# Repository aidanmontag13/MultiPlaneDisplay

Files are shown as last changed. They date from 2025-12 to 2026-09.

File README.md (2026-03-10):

# MultiPlaneDisplay

<p align="center">
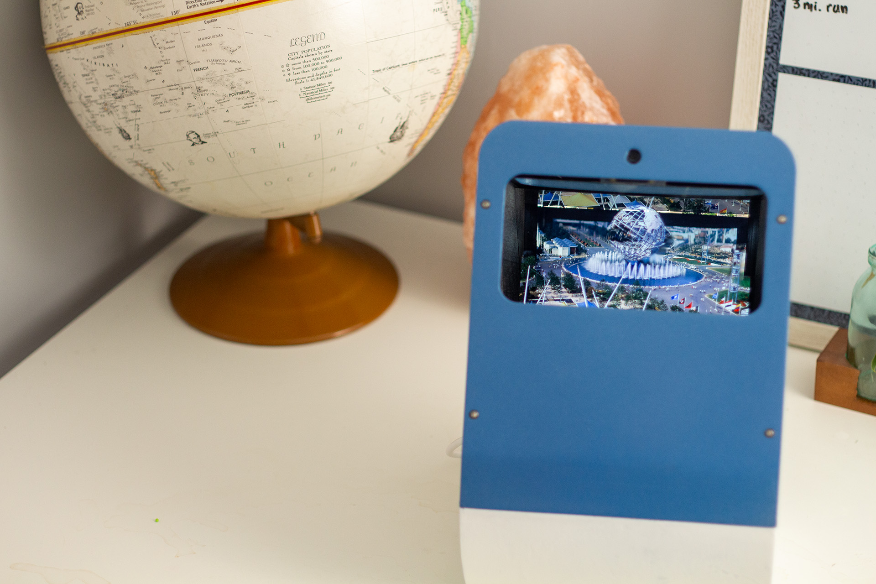
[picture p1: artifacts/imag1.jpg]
  
</p>

# How does it work?
Multi-Plane Display uses image processing and Pepper's Ghost illusions to enable any photo to be viewed with real depth, creating a "2 and a half D" Illusion.
<p align="center">
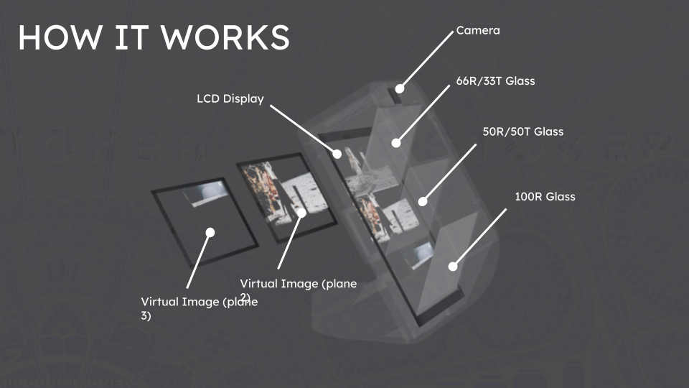
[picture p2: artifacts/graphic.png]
  
</p>

## Workflow

1. **Depth segmentation**  
   A depth map is extracted from the image using *Depth Anything v2* and used to segment the scene into **foreground**, **middleground**, and **background** layers.

2. **Viewer tracking**  
   Monocular head tracking estimates the viewer’s position relative to the display.

3. **Shadow correction**  
   Shadow maps are dynamically adjusted based on the viewer’s position to prevent off-axis ghosting artifacts.

4. **Optical display**  
   The layered images are displayed through a parascope mirror array, producing the virtual display stacking effect.
   
<table align="center">
  <tr>
    <td align="center">
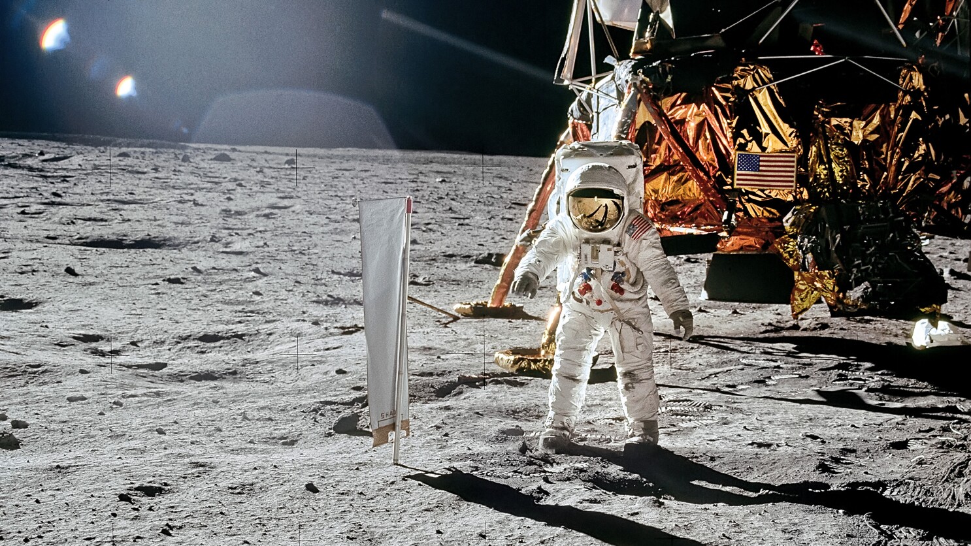
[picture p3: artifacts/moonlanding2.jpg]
      <br>
      <sub>Input Image</sub>
    </td>
    <td align="center">
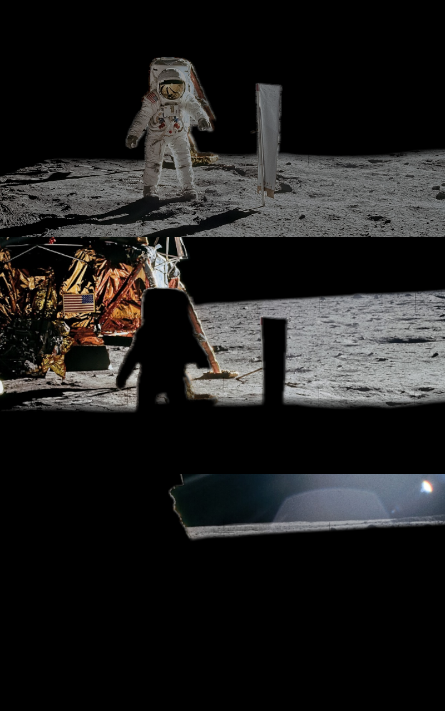
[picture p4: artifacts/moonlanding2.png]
      <br>
      <sub>Processed Image</sub>
    </td>
    <td width="40"></td>
    <td align="center">
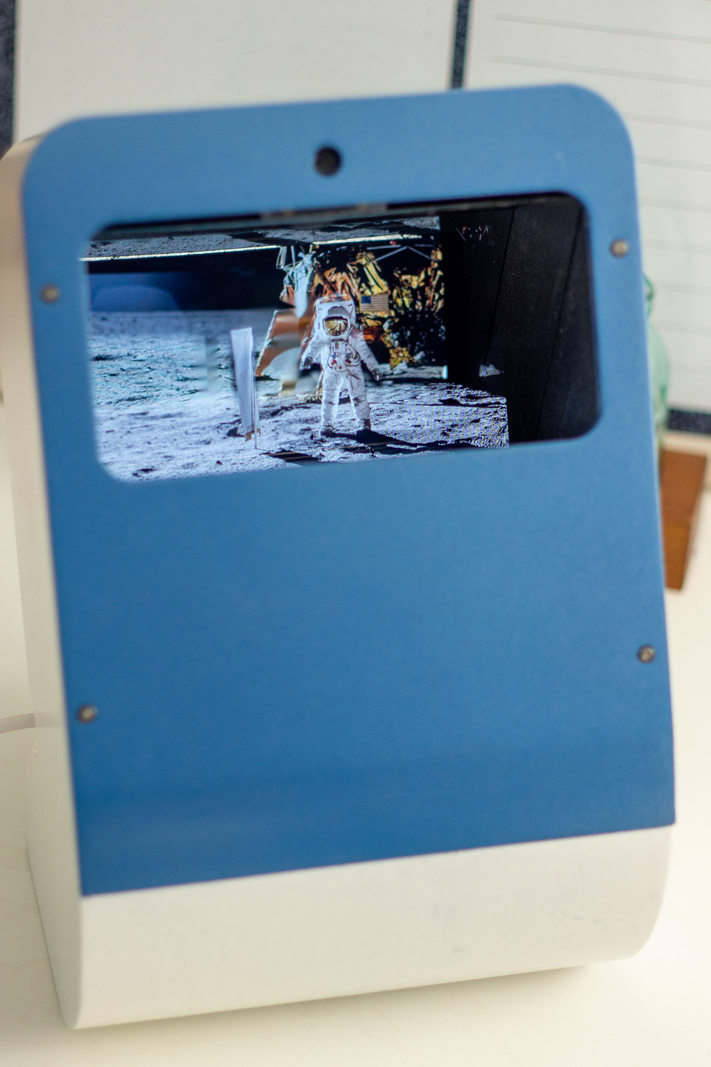
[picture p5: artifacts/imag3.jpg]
      <br>
      <sub>Viewable Result</sub>
    </td>
  </tr>
</table>

## Gallery
<p align="center">
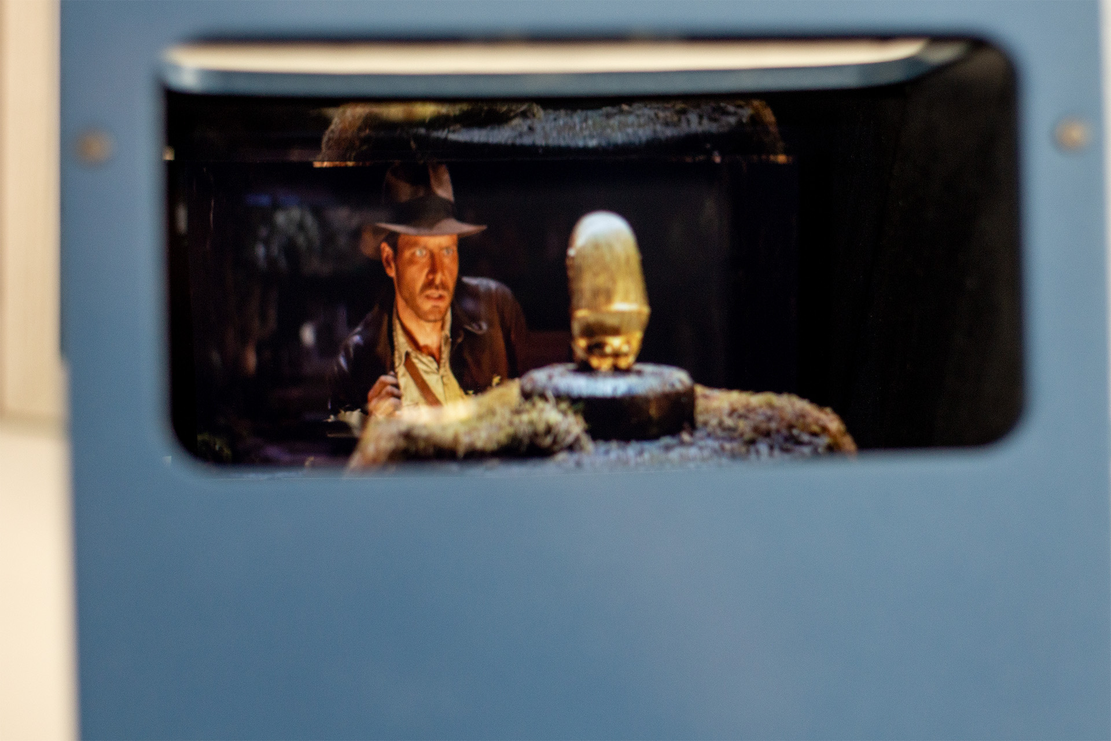
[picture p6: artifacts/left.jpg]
  
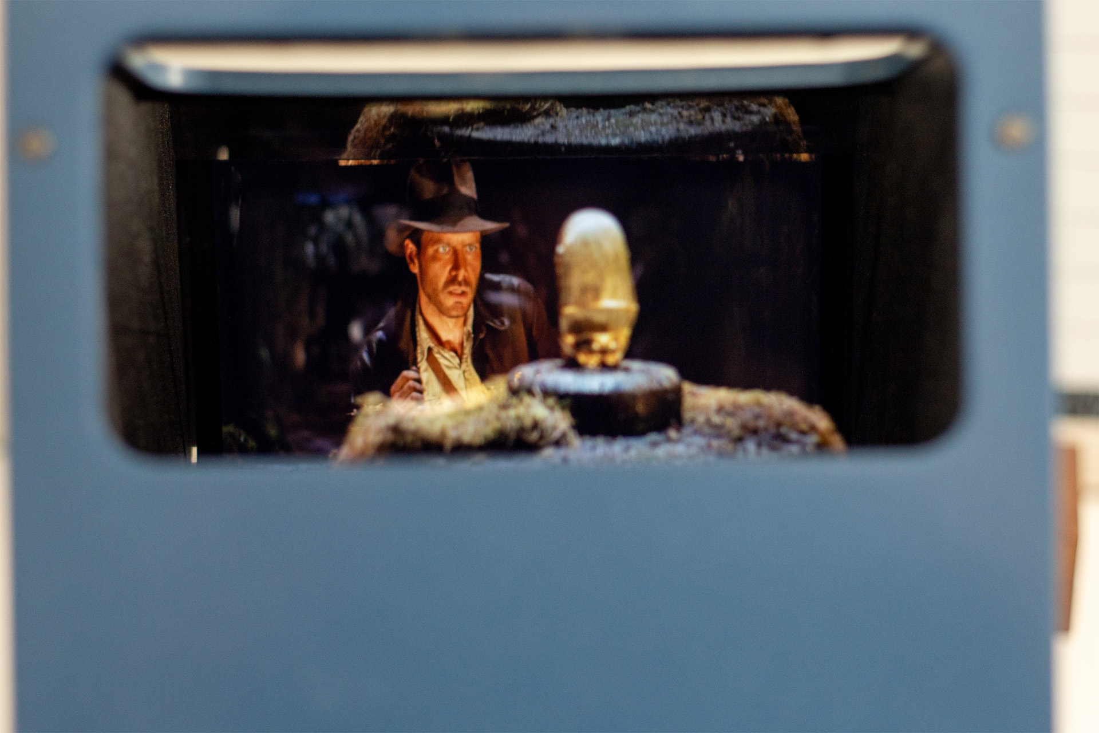
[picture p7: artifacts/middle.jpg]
  
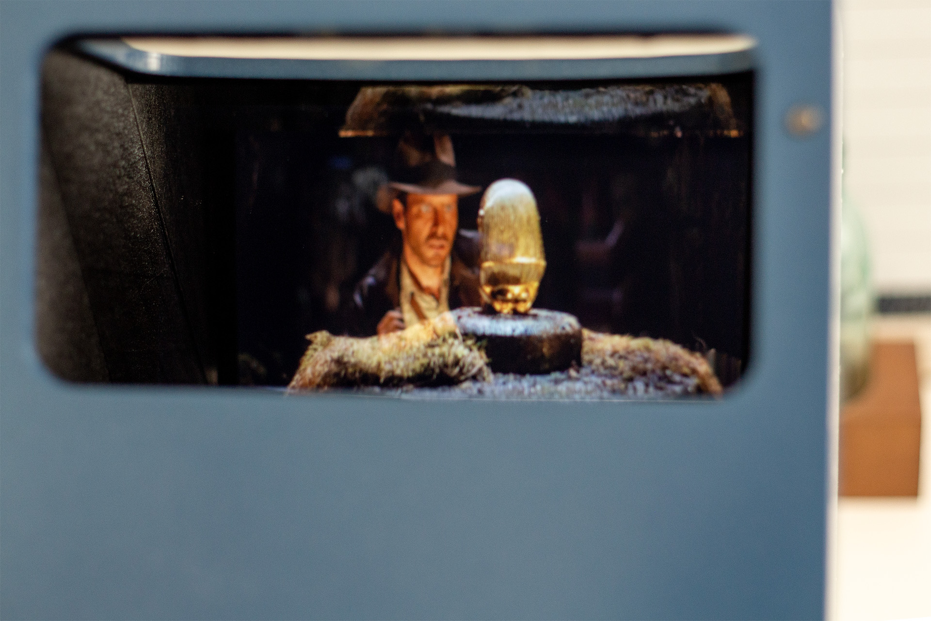
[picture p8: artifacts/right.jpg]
  
</p>

<p align="center">
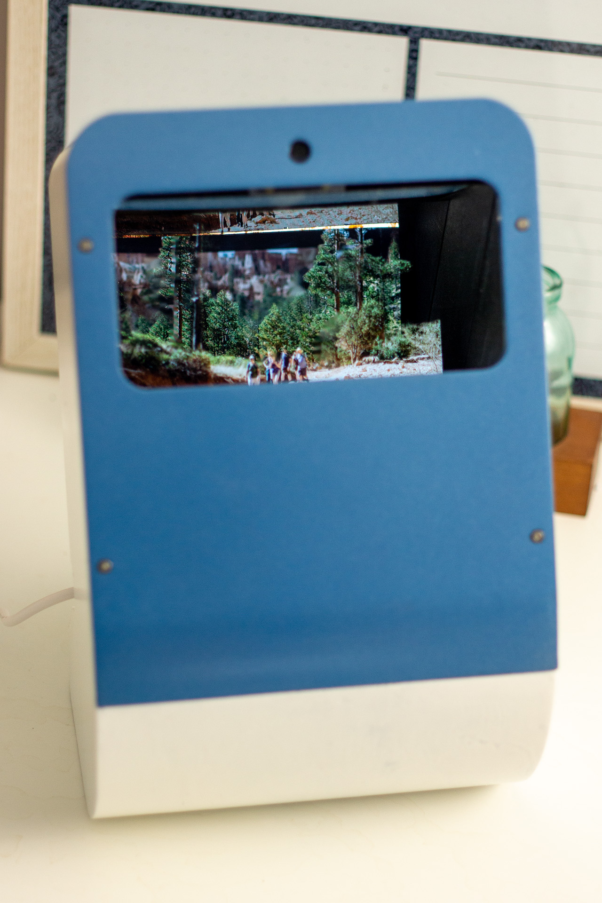
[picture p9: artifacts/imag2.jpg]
  
</p>

## Features
- Automatic image processing with input from USB drive
- Compatibility with .jpg, .jpeg, .png, and .tiff
- Automated occlusion maps with real-time headtracking
- Automatic Display turn-off and idle mode when unobserved for 30 seconds

## Parts List

- Waveshare 10.1" Display  https://a.co/d/bgIxvvW
- Raspberry Pi 5  https://a.co/d/f5K5WJR
- Cooling Fan  https://a.co/d/cPdcFge
- Semi-reflective acrylic (162x110mm) (optimally use 66/33 and 50/50 teleprompter glass, but this stuff is cheap)  https://a.co/d/37wRoJS
- acrylic mirror  (162x110mm) https://a.co/d/5MYHUT7 
- 8MP camera  https://a.co/d/0b0CgG3
- RPi 5 PSU  https://a.co/d/g17dBXe
- Micro SD card  https://a.co/d/0lqvz4a
- USB Drive  https://a.co/d/dX8yHnJ
- 250 mm CSI cable  https://a.co/d/1fIMcX2

INSTALLATION

1. Configure the Raspberry Pi camera and display

Edit the firmware configuration file:

```
sudo nano /boot/firmware/config.txt
```

Change this line:

```
camera_auto_detect=1
```

to:

```
camera_auto_detect=0
```

Add the following lines to the bottom of the file:

```
dtoverlay=vc4-kms-v3d
dtoverlay=vc4-kms-dsi-waveshare-panel-v2,10_1_inch_a
dtoverlay=imx219,cam0
```

Save the file and reboot the system.

---

2. Install system dependencies

Update the system:

```
sudo apt update
sudo apt upgrade
```

Install required packages:

```
sudo apt install -y python3-libcamera
sudo apt install -y libcamera-apps libcamera-dev libcamera-tools
sudo apt install -y python3-picamera2
sudo apt install -y unclutter
sudo apt install -y libcap-dev
```

---

3. Clone the repository

```
git clone https://github.com/aidanmontag13/MultiPlaneDisplay.git
cd MultiPlaneDisplay
```

---

4. Create the Python environment

Create a virtual environment with access to system packages (required for libcamera):

```
python3 -m venv venv --system-site-packages
```

Activate the environment:

```
source venv/bin/activate
```

Install Python dependencies:

```
pip install -r requirements.txt
```

---

5. Install the systemd service

Move the service file:

```
sudo mv ~/MultiPlaneDisplay/run_multiplane.service /etc/systemd/system/
```

Reload systemd:

```
sudo systemctl daemon-reload
```

Start the service:

```
sudo systemctl start run_multiplane.service

sudo systemctl enable run_multiplane.service
```

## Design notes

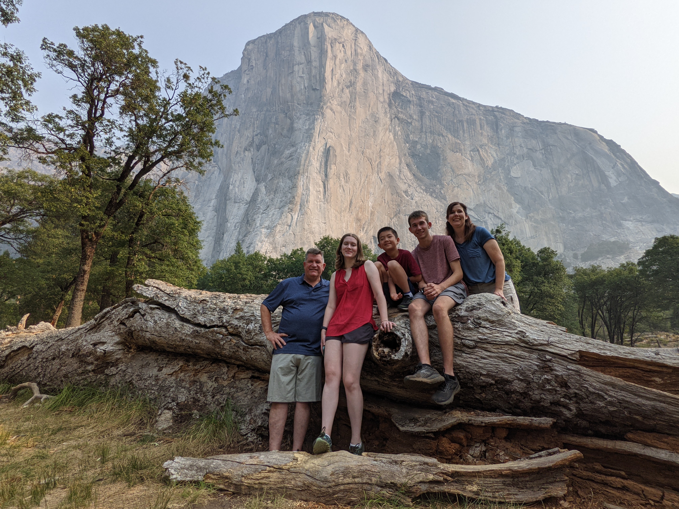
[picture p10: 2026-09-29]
image.jpg

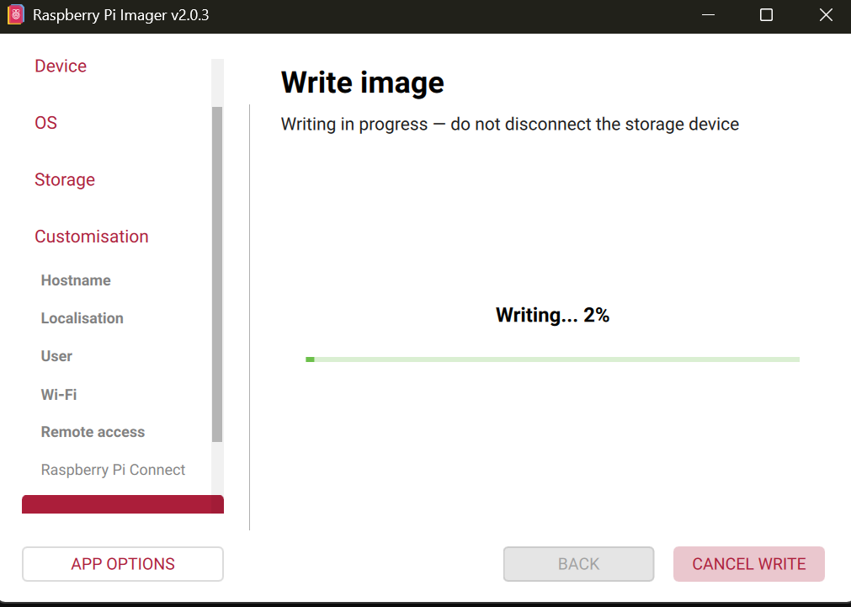
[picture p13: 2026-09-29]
artifacts/imager.png

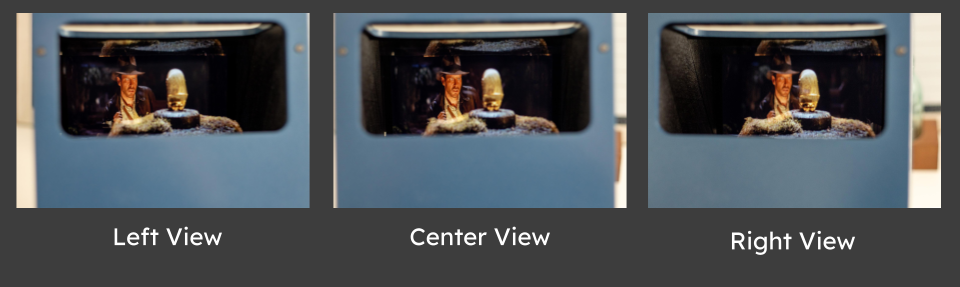
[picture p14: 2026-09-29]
artifacts/views.png

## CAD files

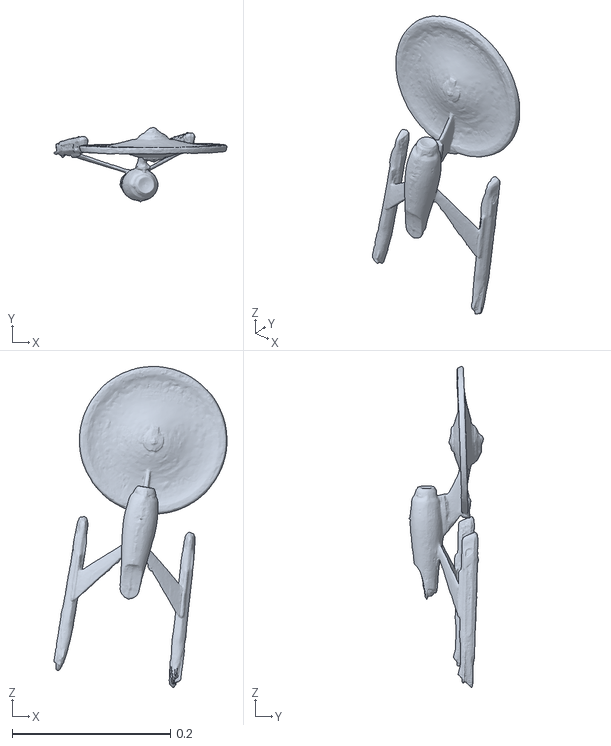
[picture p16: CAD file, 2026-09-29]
3Dmodels/model.obj
0.219 x 0.0944 x 0.406

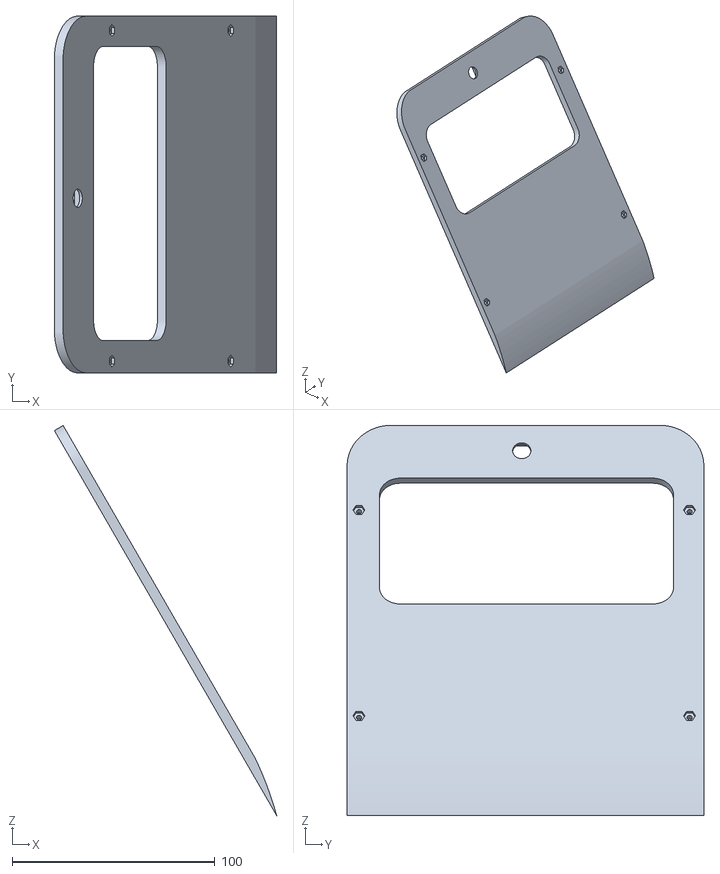
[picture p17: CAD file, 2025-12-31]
STLs/MultiplaneLid.stl
109.7 x 176.0 x 192.4

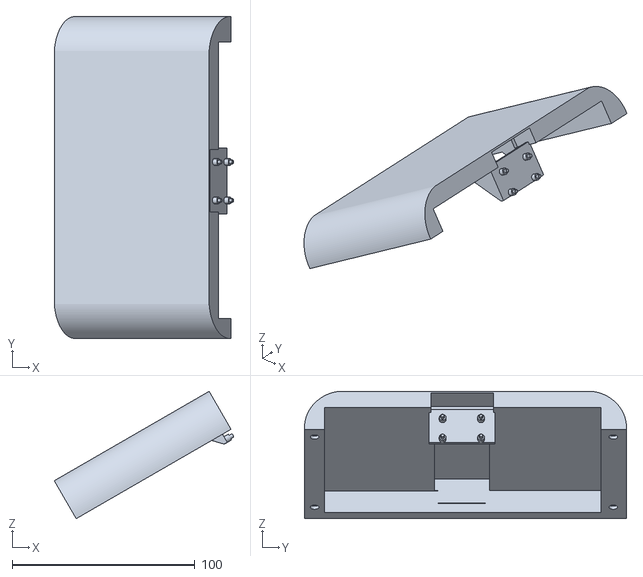
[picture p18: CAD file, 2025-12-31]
STLs/MultiplaneCap.stl
98.1 x 176.0 x 69.6

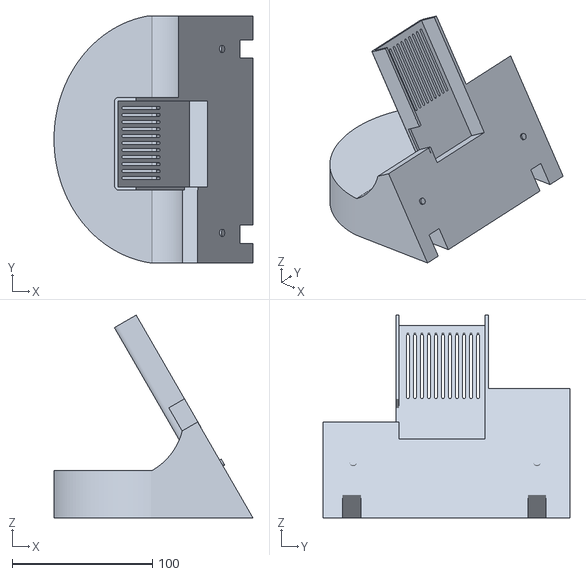
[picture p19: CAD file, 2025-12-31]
STLs/MultiplaneStand.stl
141.8 x 176.0 x 144.6

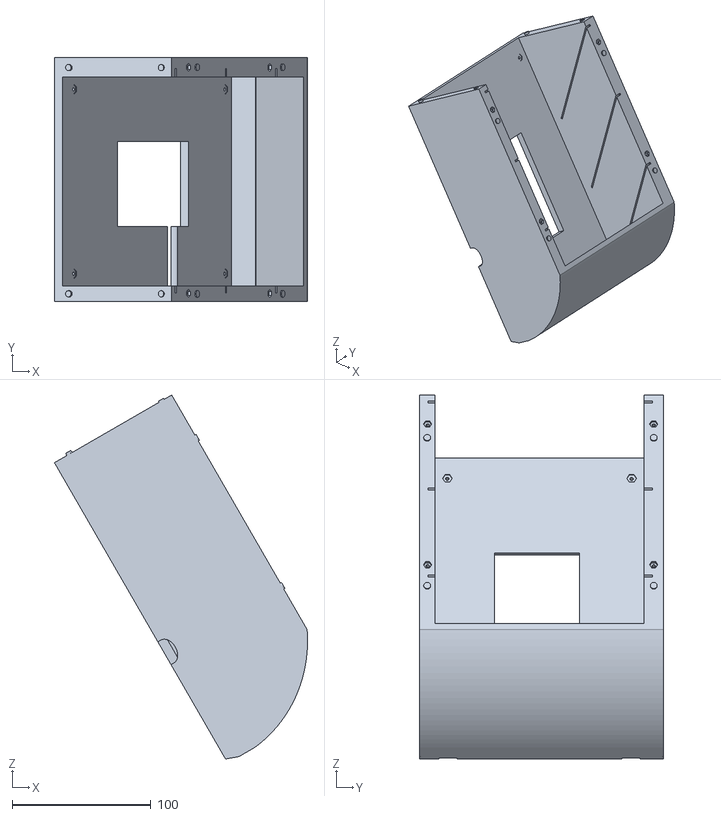
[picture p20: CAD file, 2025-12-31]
STLs/MultiplaneBase.stl
182.7 x 176.0 x 262.7

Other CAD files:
model.obj

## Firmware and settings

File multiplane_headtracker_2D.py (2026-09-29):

from math import sqrt
import onnxruntime as ort
import cv2
import numpy as np
import glob
import os
import time
import copy
import subprocess
import argparse

from skimage.filters import threshold_multiotsu

import headtracker
import queue
import threading
from ultralytics import YOLO

H = 426
W = 800

PROJECTION_DISTANCE = 0.3
SCREEN_0_DISTANCE = 0.0
SCREEN_1_DISTANCE = 0.07
SCREEN_2_DISTANCE = 0.14
DEPTH_RANGE = 0.21718
DISPLAY_WIDTH = 0.13596

ALL_DISPLAY_V_OFFSET = -10
DISPLAY_1_V_OFFSET = 10
DISPLAY_2_V_OFFSET = 30

CAMERA_V_OFFSET = 30
CAMERA_H_OFFSET = 0

CAMERA_V_OFFSET_2 = 50
CAMERA_H_OFFSET_2 = 0

DISPLAY_1_SHIFT_SCALER = 0.85
DISPLAY_2_SHIFT_SCALER = 0.4

DISPLAY_1_MAGNIFY_SCALER = 1.05
DISPLAY_2_MAGNIFY_SCALER = 1.1

ROLLOFF_A = 0.07
ROLLOFF_B = 0.15

# Load model
session = ort.InferenceSession(
    "models/depth_anything/depth_anything_v2_vits.onnx",
    providers=['CPUExecutionProvider']
)

# Get correct input name
input_name = session.get_inputs()[0].name

segment_model = YOLO("yolov8m-seg.pt")

def find_usb_images():
    user = "multiplane"
    media_root = f"/media/{user}"

    image_paths = []

    # Loop over all USB drives
    for drive in os.listdir(media_root):
        drive_path = os.path.join(media_root, drive)
        images_folder = os.path.join(drive_path)

        if os.path.isdir(images_folder):
            print(f"Found images folder on USB: {images_folder}")

            # Add all image files (jpg, png, tiff)
            for ext in ("*.jpg", "*.jpeg", "*.png", "*.tif", "*.tiff"):
                image_paths.extend(glob.glob(os.path.join(images_folder, ext)))
        else:
            print(f"No images folder found on USB: {drive_path}")
            continue

    return image_paths

def resize_and_crop(img):
    h, w = img.shape[:2]

    if w/h < 1:
        border_size = int((h - w * 1) / 2)
        img = cv2.copyMakeBorder(
            img, 0, 0, border_size, border_size,
        borderType=cv2.BORDER_CONSTANT,
        value=[0, 0, 0]
    )

    h, w = img.shape[:2]
    
    # Compute scale factor to cover the target
    scale = W / w
    
    # Resize image
    new_w = int(w * scale)
    new_h = int(h * scale)
    #print(f"Resizing from ({w}, {h}) to ({new_w}, {new_h})")
    if w / h > W / H:
        resized = cv2.resize(img, (new_w, H), interpolation=cv2.INTER_LINEAR)
        start_x = (new_w - W) // 2
        cropped = resized[:, start_x:start_x + W]
    else:
        resized = cv2.resize(img, (W, new_h), interpolation=cv2.INTER_LINEAR)
        start_y = (new_h - H) // 2
        cropped = resized[start_y:start_y + H, :]
    
    return cropped

def preprocess(image):
    img = cv2.cvtColor(image, cv2.COLOR_BGR2RGB)
    img = cv2.resize(img, (518, 518))
    img = img.astype(np.float32) / 255.0

    # model normalization
    mean = np.array([0.5, 0.5, 0.5], dtype=np.float32)
    std  = np.array([0.5, 0.5, 0.5], dtype=np.float32)
    img = (img - mean) / std

    img = img.transpose(2, 0, 1)  # HWC → CHW
    img = img[None, ...]          # add batch dim
    return img

def infer(inp):
    out = session.run(None, {input_name: inp})
    depth = out[0][0]

    # rescale depth for saving
    depth = (depth - depth.min()) / (depth.max() - depth.min())
    return depth

def despeckle(mask, kernel_size):
    kernel = np.ones((kernel_size,kernel_size), np.uint8)   # or (5,5) depending on outline thickness
    mask = mask * -1 + 1
    mask = (mask * 255).astype(np.uint8)
    closed = cv2.morphologyEx(mask, cv2.MORPH_CLOSE, kernel)
    mask = (closed.astype(np.float32)) / 255.0
    mask = mask * -1 + 1
    return mask

def blur_and_dilate(mask, blur_size):
    mask = mask * -1 + 1
    kernel = np.ones((int(blur_size * 0.2), int(blur_size * 0.8)), np.uint8)
    mask_uint8 = (mask * 255).astype(np.uint8)
    expanded = cv2.dilate(mask_uint8, kernel)
    mask = expanded.astype(np.float32) / 255.0
    mask = mask * -1 + 1
    mask = cv2.GaussianBlur(mask, (blur_size * 3, blur_size), 0)
    return mask

def create_mask(depth, low_thresh, high_thresh, rolloff_a, rolloff_b, blur):
    mask = np.zeros_like(depth, dtype=np.float32)

    if rolloff_a == 0 and rolloff_b == 0:
        mask = ((depth >= low_thresh) & (depth <= high_thresh)).astype(np.float32)
        mask = blur_and_dilate(mask, blur)
        mask = despeckle(mask, kernel_size=3)
        mask = cv2.resize(mask, (W, H), interpolation=cv2.INTER_LINEAR)
        return mask
    
    lower_ramp = (depth - (low_thresh - 0.5 * rolloff_a)) / (rolloff_a + 1e-6)
    lower_ramp = np.clip(lower_ramp, 0, 1)
    
    upper_ramp = ((high_thresh + 0.5 * rolloff_b) - depth) / (rolloff_b + 1e-6)
    upper_ramp = np.clip(upper_ramp, 0, 1)
    
    if low_thresh == 0:
        mask = upper_ramp
    elif high_thresh == 1:
        mask = lower_ramp
    else:
        mask = np.minimum(lower_ramp, upper_ramp)

    mask = despeckle(mask, kernel_size=3)
    mask = blur_and_dilate(mask, blur)

    mask = cv2.resize(mask, (W, H), interpolation=cv2.INTER_LINEAR)
    
    return mask

def apply_mask(image, mask):
    mask = np.repeat(mask[:, :, np.newaxis], 3, axis=2)
    masked_image = image * mask
    return masked_image

def create_segmentation_mask(image):
    image = cv2.resize(image, (640, 640))

    results = segment_model(image)
    result = results[0]

    if result.masks is None:
        return None

    masks = result.masks.data.cpu().numpy()
    mask = (np.sum(masks, axis=0)).astype(np.float32)
    mask = np.clip(mask, 0, 1).astype(np.float32)
    #mask = cv2.GaussianBlur(mask, (25, 25), 0)

    return masks

def apply_segmentation_mask(mask, segmentation_masks, blur):
    if segmentation_masks is None:
        return mask

    solid_mask = mask.copy()

    for segmentation_mask in segmentation_masks:
        segmentation_mask = segmentation_mask.astype(np.float32)
        segmentation_mask = cv2.resize(segmentation_mask, (mask.shape[1], mask.shape[0]), interpolation=cv2.INTER_LINEAR)

        ratio = np.sum(segmentation_mask * mask) / (np.sum(segmentation_mask))
        print("ratio is:", ratio)

        if ratio > 0.5 and ratio < 0.9:
            solid_mask = np.where((segmentation_mask >= solid_mask) & (solid_mask > 0.1), segmentation_mask, solid_mask)

        if ratio <= 0.5:
            solid_mask = np.where((segmentation_mask >= solid_mask) & (solid_mask > 0.1), 0, solid_mask)

        solid_mask = np.clip(solid_mask, 0, 1)
        solid_mask = cv2.GaussianBlur(solid_mask, (blur * 3, blur), 0)

    stacked_vis = np.vstack((mask, solid_mask))
    #cv2.imshow("stacked visualization", ((stacked_vis ** 2.2) * 255).astype(np.uint8))
    #cv2.waitKey(0)
    #cv2.destroyAllWindows()
        
    return solid_mask

def inpaint_mask(image, mask):
    w, h = image.shape[1], image.shape[0]
    mask = 1.0 - mask
    mask = cv2.resize(mask, (w, h), interpolation=cv2.INTER_LINEAR)
    mask_uint8 = (mask * 255).astype(np.uint8)
    kernel = np.ones((int(5), int(5)), np.uint8)
    mask = cv2.dilate(mask_uint8, kernel)
    inpainted = cv2.inpaint((image * 255).astype(np.uint8), mask_uint8, 5, cv2.INPAINT_NS)
    inpainted = inpainted.astype(np.float32) / 255.0
    return inpainted
    
def stack_images(foreground, middleground, background):
    middleground_M = np.float32([[1, 0, 0],
                [0, 1, DISPLAY_1_V_OFFSET]])

    middleground = cv2.warpAffine(middleground, middleground_M, (W, H),
                          flags=cv2.INTER_LINEAR,
                          borderMode=cv2.BORDER_CONSTANT,
                          borderValue=0)
    
    background_M = np.float32([[1, 0, 0],
                [0, 1, DISPLAY_2_V_OFFSET]])

    background = cv2.warpAffine(background, background_M, (W, H),
                          flags=cv2.INTER_LINEAR,
                          borderMode=cv2.BORDER_CONSTANT,
                          borderValue=0)

    foreground = foreground * (0.7, 1.0, 1.3)
    middleground = middleground * (0.33, 0.33, 0.33)
    background = background * (0.7, 1.0, 1.2)
    combined = np.vstack((foreground, middleground, background))
    combined_M = np.float32([[1, 0, 0],
                [0, 1, ALL_DISPLAY_V_OFFSET]])

    combined = cv2.warpAffine(combined, combined_M, (W, H * 3),
                          flags=cv2.INTER_LINEAR,
                          borderMode=cv2.BORDER_CONSTANT,
                          borderValue=0)

    combined = np.clip(combined, 0, 1)
    #combined = combined.astype(np.float32)
    #combined = cv2.rotate(combined, cv2.ROTATE_90_CLOCKWISE)
    #print("combined shape:", combined.shape)
    combined = cv2.resize(combined, (800, 1280), interpolation=cv2.INTER_LINEAR)
    return combined

def prepare_planes(image_path):
    image = cv2.imread(image_path)
    image = resize_and_crop(image)
    linear_float_image = (image.astype(np.float32) / 255.0) ** 2.2
    inp = preprocess(image)
    depth = infer(inp)
    depth = 1 - depth
    depth = depth ** (3.0)
    ot1, ot2 = threshold_multiotsu(depth, classes=3)

    segment_masks = create_segmentation_mask(image)

    binary_middleground_mask = create_mask(depth, ot1 - ROLLOFF_A / 2, 1, 0.0, 0.0, 1)
    binary_middleground_mask = apply_segmentation_mask(binary_middleground_mask, segment_masks, 1)

    binary_background_mask = create_mask(depth, ot2 - ROLLOFF_B / 2, 1, 0.0, 0.0, 1)

    middleground = inpaint_mask(linear_float_image, binary_middleground_mask)
    background = inpaint_mask(linear_float_image, binary_background_mask)

    print("depth type:", depth.dtype, "min:", depth.min(), "max:", depth.max())
    print("depth size:", depth.shape)
    middleground_depth = inpaint_mask(depth, binary_middleground_mask)

    foreground_mask = create_mask(depth, 0, ot1, 0.0, ROLLOFF_A, 3) #5)
    foreground_mask = apply_segmentation_mask(foreground_mask, segment_masks, 3)

    middleground_front_mask = create_mask(depth, ot1, 1.0, ROLLOFF_A, ROLLOFF_B, 21) #15)
    middleground_front_mask = apply_segmentation_mask(middleground_front_mask, segment_masks, 21)

    middleground_back_mask = create_mask(middleground_depth, 0.0, ot2, ROLLOFF_A, ROLLOFF_B, 3) #21)
    middleground_back_mask = apply_segmentation_mask(middleground_back_mask, segment_masks, 3)

    background_mask = create_mask(depth, ot2, 1.0, ROLLOFF_B, 0.0, 21) #,21)
    background_mask = apply_segmentation_mask(background_mask, segment_masks, 21)

    foreground = apply_mask(linear_float_image, foreground_mask)
    middleground = apply_mask(middleground, middleground_back_mask)

    return foreground, middleground, background, linear_float_image, middleground_front_mask, background_mask
    
def check_if_planes_exist(base_path):
    dir_name = os.path.dirname(base_path)
    file_name = os.path.basename(base_path)
    name, ext = os.path.splitext(file_name)

    new_path = os.path.join(dir_name, "processed_images", name)

    required_files = ["foreground.tiff", "middleground.tiff", "background.tiff", "merged.tiff", "middleground_mask.tiff", "background_mask.tiff"]

    for req_file in required_files:
        if not os.path.exists(os.path.join(new_path, req_file)):
            return False

    return True

def save_planes(foreground, middleground, background, merged, middleground_front_mask, background_mask, base_path):
    dir_name = os.path.dirname(base_path)
    file_name = os.path.basename(base_path)
    name, ext = os.path.splitext(file_name)

    new_path = os.path.join(dir_name, "processed_images", name)
    os.makedirs(new_path, exist_ok=True)

    print("saving planes to:", new_path)
    print("saving foreground to ", os.path.join(new_path, "foreground.tiff"))
    cv2.imwrite(os.path.join(new_path, "foreground.tiff"), (foreground * 65535).astype(np.uint16))
    cv2.imwrite(os.path.join(new_path, "middleground.tiff"), (middleground * 65535).astype(np.uint16))
    cv2.imwrite(os.path.join(new_path, "background.tiff"), (background * 65535).astype(np.uint16))
    cv2.imwrite(os.path.join(new_path, "merged.tiff"), (merged * 65535).astype(np.uint16))
    cv2.imwrite(os.path.join(new_path, "middleground_mask.tiff"), (middleground_front_mask * 65535).astype(np.uint16))
    cv2.imwrite(os.path.join(new_path, "background_mask.tiff"), (background_mask * 65535).astype(np.uint16))

def load_planes(base_path):
    dir_name = os.path.dirname(base_path)
    file_name = os.path.basename(base_path)
    name, ext = os.path.splitext(file_name)

    new_path = os.path.join(dir_name, "processed_images", name)
    
    foreground = cv2.imread(os.path.join(new_path, "foreground.tiff"), cv2.IMREAD_UNCHANGED).astype(np.float32) / 65535.0
    middleground = cv2.imread(os.path.join(new_path, "middleground.tiff"), cv2.IMREAD_UNCHANGED).astype(np.float32) / 65535.0
    background = cv2.imread(os.path.join(new_path, "background.tiff"), cv2.IMREAD_UNCHANGED).astype(np.float32) / 65535.0
    merged = cv2.imread(os.path.join(new_path, "merged.tiff"), cv2.IMREAD_UNCHANGED).astype(np.float32) / 65535.0
    middleground_mask = cv2.imread(os.path.join(new_path, "middleground_mask.tiff"), cv2.IMREAD_UNCHANGED).astype(np.float32) / 65535.0
    background_mask = cv2.imread(os.path.join(new_path, "background_mask.tiff"), cv2.IMREAD_UNCHANGED).astype(np.float32) / 65535.0

    return foreground, middleground, background, merged, middleground_mask, background_mask

def shift_mask(mask, screen_distance, viewer_position, max_shift, x_offset, y_offset, scaler):
    x, y, z = viewer_position

    x = -x + 0.00
    y = y + 0.08
    z = z + 0.06

    shift_x = (x/y) * screen_distance * (W / DISPLAY_WIDTH)
    shift_y = ((z/y) * screen_distance) * (W / DISPLAY_WIDTH)

    shift_x = np.round((shift_x + x_offset) * scaler)
    shift_y = np.round((shift_y + y_offset) * scaler)

    if shift_x > max_shift:
        shift_x = max_shift
    if shift_x < -max_shift:
        shift_x = -max_shift

    if shift_y > max_shift:
        shift_y = max_shift
    if shift_y < -max_shift:
        shift_y = -max_shift    

    M = np.float32([[1, 0, shift_x],
                [0, 1, shift_y]])

    shifted_mask = cv2.warpAffine(mask, M, (W, H),
                          flags=cv2.INTER_LINEAR,
                          borderMode=cv2.BORDER_REPLICATE,
                          borderValue=0)

    return shifted_mask

def magnify_image(image, screen_distance, viewer_position, scaler):
    x, y, z = viewer_position

    viewer_distance = sqrt(x**2 + y**2 + z**2)

    magnification = ((viewer_distance + screen_distance) / (viewer_distance)) * scaler

    new_h = int(H * magnification)
    new_w = int(W * magnification)

    magnified = cv2.resize(image, (new_w, new_h), interpolation=cv2.INTER_LINEAR)
    start_y = (new_h - H) // 2
    start_x = (new_w - W) // 2
    cropped = magnified[start_y:start_y + H, start_x:start_x + W]

    return cropped

def interpolate_position(position, previous_position, alpha):

    if previous_position is None:
        return position
    else:
        smoothed_position = [
            alpha * position[0] + (1 - alpha) * previous_position[0],
            alpha * position[1] + (1 - alpha) * previous_position[1],
            alpha * position[2] + (1 - alpha) * previous_position[2],
        ]

    return smoothed_position

def renderer_worker(foreground, middleground, background, merged, middleground_mask, background_mask, position_queue, render_queue, render_stop_event):
    alpha = 0.3
    smoothed_position = None
    target_position = None

    flat_image = np.zeros((1280, 800, 3), dtype=np.float32)
    merged_srgb = (merged * (0.7, 1.0, 1.3)) ** (1 / 2.2)
    flat_image[0:426, 0:800] = merged_srgb
    flat_image_M = np.float32([[1, 0, 0],
                [0, 1, ALL_DISPLAY_V_OFFSET]])

    flat_image = cv2.warpAffine(flat_image, flat_image_M, flat_image.shape[1::-1],
                          flags=cv2.INTER_LINEAR,
                          borderMode=cv2.BORDER_CONSTANT,
                          borderValue=0)

    render_queue.put(flat_image)
    time.sleep(3)

    while not render_stop_event.is_set():
        # Try to get a new target position
        start_time = time.time()
        try:
            new_position = position_queue.get_nowait()
            if new_position is not None:
                target_position = list(new_position)
                print("got position", new_position)
            position_queue.task_done()
        except queue.Empty:
            pass  # no new position, keep last target

        # Interpolate toward target
        smoothed_position = interpolate_position(target_position, smoothed_position, alpha)

        x, y, z = smoothed_position

        shifted_middleground_mask = shift_mask(middleground_mask, SCREEN_1_DISTANCE, [x, y, z], 100, CAMERA_H_OFFSET, CAMERA_V_OFFSET, DISPLAY_1_SHIFT_SCALER)
        shifted_background_mask = shift_mask(background_mask, (SCREEN_2_DISTANCE), [x, y, z], 200, CAMERA_H_OFFSET_2, CAMERA_V_OFFSET_2, DISPLAY_2_SHIFT_SCALER)

        masked_middleground = apply_mask(middleground, shifted_middleground_mask)
        masked_background = apply_mask(background, shifted_background_mask)

        masked_middleground = magnify_image(masked_middleground, SCREEN_1_DISTANCE, [x, y, z], DISPLAY_1_MAGNIFY_SCALER)
        masked_background = magnify_image(masked_background, SCREEN_2_DISTANCE, [x, y, z], DISPLAY_2_MAGNIFY_SCALER)

        combined_image = stack_images(foreground, masked_middleground, masked_background)

        combined_image_srgb = combined_image ** (1 / 2.2)

        try:
            render_queue.put_nowait(combined_image_srgb)
        except queue.Full:
            pass
        end_time = time.time()
        elapsed_time = end_time - start_time
        print(f"Render time: {elapsed_time:.4f}s")

    black_image = np.zeros((1280, 800, 3), dtype=np.float32)
    render_queue.put(black_image)

def display_worker(render_queue, stop_event, idle_event):
    alpha = 0.3 

    current_image = np.zeros((1280, 800, 3), dtype=np.float32)
    target_image  = np.zeros((1280, 800, 3), dtype=np.float32)

    cv2.namedWindow("combined_image", cv2.WINDOW_NORMAL)
    cv2.setWindowProperty(
        "combined_image",
        cv2.WND_PROP_FULLSCREEN,
        cv2.WINDOW_FULLSCREEN
    )

    while not stop_event.is_set():

        if idle_event.is_set():
            print("display idle on")
            time.sleep(3)
            continue
        
        start_time = time.time()
        try:
            while True:
                new_image = render_queue.get_nowait()
                if new_image is None:
                    stop_event.set()
                    break
                target_image = new_image.astype(np.float32)
                render_queue.task_done()
        except queue.Empty:
            pass
        
        current_image += alpha * (target_image - current_image)
        display = np.clip(current_image * 255, 0, 255).astype(np.uint8)
        cv2.imshow("combined_image", display)
        
        if cv2.waitKey(1) & 0xFF == ord('q'):
            stop_event.set()
            break

        end_time = time.time()
        elapsed_time = end_time - start_time

        #print(f"Frame time: {elapsed_time:.4f}s")

def main():
    parser = argparse.ArgumentParser()

    parser.add_argument("--aimode", action="store_true")

    aimode = parser.parse_args().aimode

    subprocess.Popen(["unclutter", "-idle", "0", "-root"])

    headtracker.set_backlight(255)
    images = find_usb_images()

    cap, model, camera_matrix, dist_coeffs = headtracker.initialize_headtracker(aimode=aimode)
    position_queue = queue.Queue(maxsize=1)
    render_queue = queue.Queue(maxsize=2)

    stop_event = threading.Event()
    render_stop_event = threading.Event()
    idle_event = threading.Event()
    
    headtracker_thread = threading.Thread(
        target=headtracker.headtracker_worker,
        args=(cap, model, aimode, camera_matrix, dist_coeffs, position_queue, stop_event, idle_event),
        daemon=False,
    )

    display_thread = threading.Thread(
        target=display_worker,
        args=(render_queue, stop_event, idle_event),
        daemon=False,
    )

    headtracker_thread.start()
    display_thread.start()

    for image_path in images:
        if idle_event.is_set():
            print(" renderer idle on")
            time.sleep(3)
            continue

        checked_planes = check_if_planes_exist(image_path)

        #checked_planes = False # force reprocessing for testing

        if not checked_planes:
            print("preparing planes for image:", image_path)
            foreground, middleground, background, merged, middleground_mask, background_mask = prepare_planes(image_path)

            save_planes(foreground, middleground, background, merged, middleground_mask, background_mask, os.path.splitext(image_path)[0])

        else:
            print("loading planes for image:", image_path)
            foreground, middleground, background, merged, middleground_mask, background_mask = load_planes(image_path)

        renderer_thread = threading.Thread(
            target=renderer_worker,
            args=(foreground, middleground, background, merged, middleground_mask, background_mask, position_queue, render_queue, render_stop_event),
            daemon=False,
        )

        renderer_thread.start()

        time.sleep(20)
    
        render_stop_event.set()
        renderer_thread.join()
        render_stop_event.clear()

    stop_event.set()
    position_queue.put(None)
    headtracker_thread.join()
    display_thread.join()
    cv2.destroyAllWindows()

if __name__ == "__main__":
    main()

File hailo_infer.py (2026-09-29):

from typing import Tuple, Dict, List
import os
from typing import Callable, Optional
from functools import partial
import numpy as np
import cv2
from hailo_platform import (HEF, VDevice,FormatType, HailoSchedulingAlgorithm)
from pose_estimation_utils import PoseEstPostProcessing
from hailo_platform.pyhailort.pyhailort import FormatOrder

class HailoInfer:
    def __init__(
        self, hef_path: str, batch_size: int = 1,
            input_type: Optional[str] = None, output_type: Optional[str] = None,
            priority: Optional[int] = 0) -> None:

        """
        Initialize the HailoAsyncInference class to perform asynchronous inference using a Hailo HEF model.

        Args:
            hef_path (str): Path to the HEF model file.
            batch_size (optional[int]): Number of inputs processed per inference. Defaults to 1.
            input_type (Optional[str], optional): Input data type format. Common values: 'UINT8', 'UINT16', 'FLOAT32'.
            output_type (Optional[str], optional): Output data type format. Common values: 'UINT8', 'UINT16', 'FLOAT32'.
            priority (optional[int]): Scheduler priority value for the model within the shared VDevice context. Defaults to 0.
        """
        params = VDevice.create_params()
        # Set the scheduling algorithm to round-robin to activate the scheduler
        params.scheduling_algorithm = HailoSchedulingAlgorithm.ROUND_ROBIN
        params.group_id = "SHARED"
        vDevice = VDevice(params)

        self.target = vDevice
        hef_path = os.fspath(hef_path)
        self.hef = HEF(hef_path)

        self.infer_model = self.target.create_infer_model(hef_path)
        self.infer_model.set_batch_size(batch_size)

        self._set_input_type(input_type)
        self._set_output_type(output_type)

        self.config_ctx = self.infer_model.configure()
        self.configured_model = self.config_ctx.__enter__()
        self.configured_model.set_scheduler_priority(priority)
        self.last_infer_job = None


    def _set_input_type(self, input_type: Optional[str] = None) -> None:
        """
        Set the input type for the HEF model. If the model has multiple inputs,
        it will set the same type of all of them.

        Args:
            input_type (Optional[str]): Format type of the input stream.
        """

        if input_type is not None:
            self.infer_model.input().set_format_type(getattr(FormatType, input_type))

    def _set_output_type(self, output_type: Optional[str] = None) -> None:
        """
        Set the output type for each model output.

        Args:
            output_type (Optional[str]): Desired output data type. Common values:
                'UINT8', 'UINT16', 'FLOAT32'.
        """

        self.nms_postprocess_enabled = False

        # If the model uses HAILO_NMS_WITH_BYTE_MASK format (e.g.,instance segmentation),
        if self.infer_model.outputs[0].format.order == FormatOrder.HAILO_NMS_WITH_BYTE_MASK:
            # Use UINT8 and skip setting output formats
            self.nms_postprocess_enabled = True
            self.output_type = self._output_data_type2dict("UINT8")
            return

        # Otherwise, set the format type based on the provided output_type argument
        self.output_type = self._output_data_type2dict(output_type)

        # Apply format to each output layer
        for name, dtype in self.output_type.items():
            self.infer_model.output(name).set_format_type(getattr(FormatType, dtype))


    def get_vstream_info(self) -> Tuple[list, list]:

        """
        Get information about input and output stream layers.

        Returns:
            Tuple[list, list]: List of input stream layer information, List of 
                               output stream layer information.
        """
        return (
            self.hef.get_input_vstream_infos(), 
            self.hef.get_output_vstream_infos()
        )

    def get_hef(self) -> HEF:
        """
        Get a HEF instance
        
        Returns:
            HEF: A HEF (Hailo Executable File) containing the model.
        """
        return self.hef

    def get_input_shape(self) -> Tuple[int, ...]:
        """
        Get the shape of the model's input layer.

        Returns:
            Tuple[int, ...]: Shape of the model's input layer.
        """
        return self.hef.get_input_vstream_infos()[0].shape  # Assumes one input


    def run(self, input_batch: List[np.ndarray], inference_callback_fn) -> object:
        """
        Run an asynchronous inference job on a batch of preprocessed inputs.

        This method reuses a preconfigured model (no reconfiguration overhead),
        prepares input/output bindings, launches async inference, and returns
        the job handle so that the caller can wait on it if needed.

        Args:
            input_batch (List[np.ndarray]): A batch of preprocessed model inputs.
            inference_callback_fn (Callable): Function to be invoked when inference is complete.
                                              It receives `bindings_list` and additional context.

        Returns:
            Async job handle returned by `run_async`, which can be used to wait for completion or check status.
        """
        bindings_list = self._create_bindings(self.configured_model, input_batch)
        self.configured_model.wait_for_async_ready(timeout_ms=10000)

        # Launch async inference and attach the result handler
        self.last_infer_job = self.configured_model.run_async(
            bindings_list,
            partial(inference_callback_fn, bindings_list=bindings_list)
        )
        return self.last_infer_job

    def _create_bindings(self, configured_model, input_batch):
        """
        Create a list of input-output bindings for a batch of frames.

        Args:
            configured_model: The configured inference model.
            input_batch (List[np.ndarray]): List of input frames, preprocessed and ready.

        Returns:
            List[Bindings]: A list of bindings for each frame's input and output buffers.
        """

        def _frame_binding(frame: np.ndarray):
            output_buffers = {
                name: np.empty(
                    self.infer_model.output(name).shape,
                    dtype=(getattr(np, self.output_type[name].lower()))
                )
                for name in self.output_type
            }

            binding = configured_model.create_bindings(output_buffers=output_buffers)
            binding.input().set_buffer(np.array(frame))
            return binding

        return [_frame_binding(frame) for frame in input_batch]



    def is_nms_postprocess_enabled(self) -> bool:
        """
        Returns True if the HEF model includes an NMS postprocess node.
        """
        return self.nms_postprocess_enabled
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

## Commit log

2025-11-21 added stl
    [MultiplaneBase.stl]
2025-11-21 fix: updated display.py to work properly
    [display.py]
2025-11-21 fix: updated to work on boot
    [display.py]
2025-12-01 fix: fixed quantization issue
    [multiplane_lenticular.py]
2025-12-18 fixed dynamic for pi
    [headtracker.py, multiplane_headtracker_2D.py]
2025-12-21 fixed bug with idle time
    [headtracker.py]
2025-12-26 fine tuning and calibration stuff
2026-03-10 Add installation instructions for Raspberry Pi setup
    Added detailed installation instructions for setting up the Raspberry Pi camera and display, including configuration changes, system dependencies, repository cloning, Python environment setup, and sy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
2026-09-29 feat: added more documentation
    [model.obj]
